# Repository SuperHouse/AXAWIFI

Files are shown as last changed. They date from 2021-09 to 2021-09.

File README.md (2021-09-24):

AXA Electric Window Motor WiFi Controller (ESP8266)
===================================================
Copyright 2017-2021 SuperHouse Automation Pty Ltd  www.superhouse.tv  

An add-in board for AXA domestic electric window mechanisms, to fit
into the battery compartment in place of the AA cells that are normally
installed. It uses an ESP8266 to connect to WiFi, and can then send
control signals to the AXA window motor using LINbus.

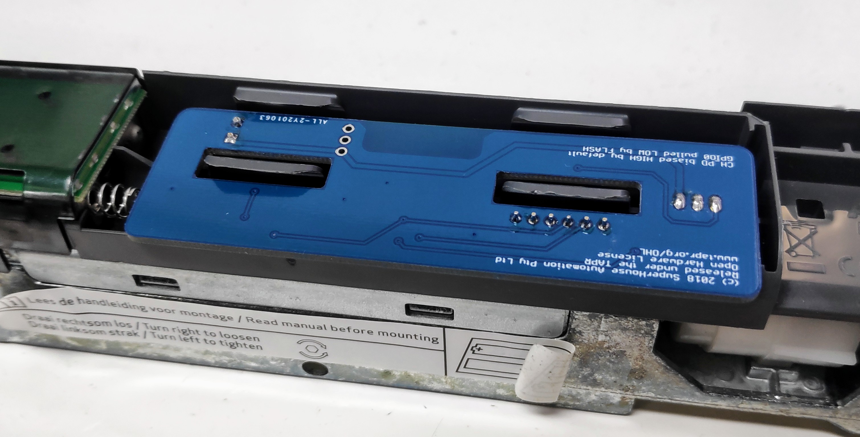
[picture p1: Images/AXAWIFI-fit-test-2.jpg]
Axa Wifi PCB


An external 12Vdc power connection is required. Power is supplied to
the Axa Wifi board, which in turn passes on power and data to the
existing controller in the window motor.

Features:

 * ESP8266 microcontroller with WiFi.
 * LIN bus interface.
 * Fits inside Axa battery compartment.

More information:

  [www.superhouse.tv/axawifi](https://www.superhouse.tv/axawifi)

INSTALLATION
------------
The design is saved as an EAGLE project. Install EAGLE and open the
files directly.

CREDITS
-------
Designed by Jonathan Oxer jon@oxer.com.au

DISTRIBUTION
------------
The specific terms of distribution of this project are governed by the
license referenced below.

LICENSE
-------
Licensed under the TAPR Open Hardware License (www.tapr.org/OHL).
The "license" folder within this repository also contains a copy of
this license in plain text format.

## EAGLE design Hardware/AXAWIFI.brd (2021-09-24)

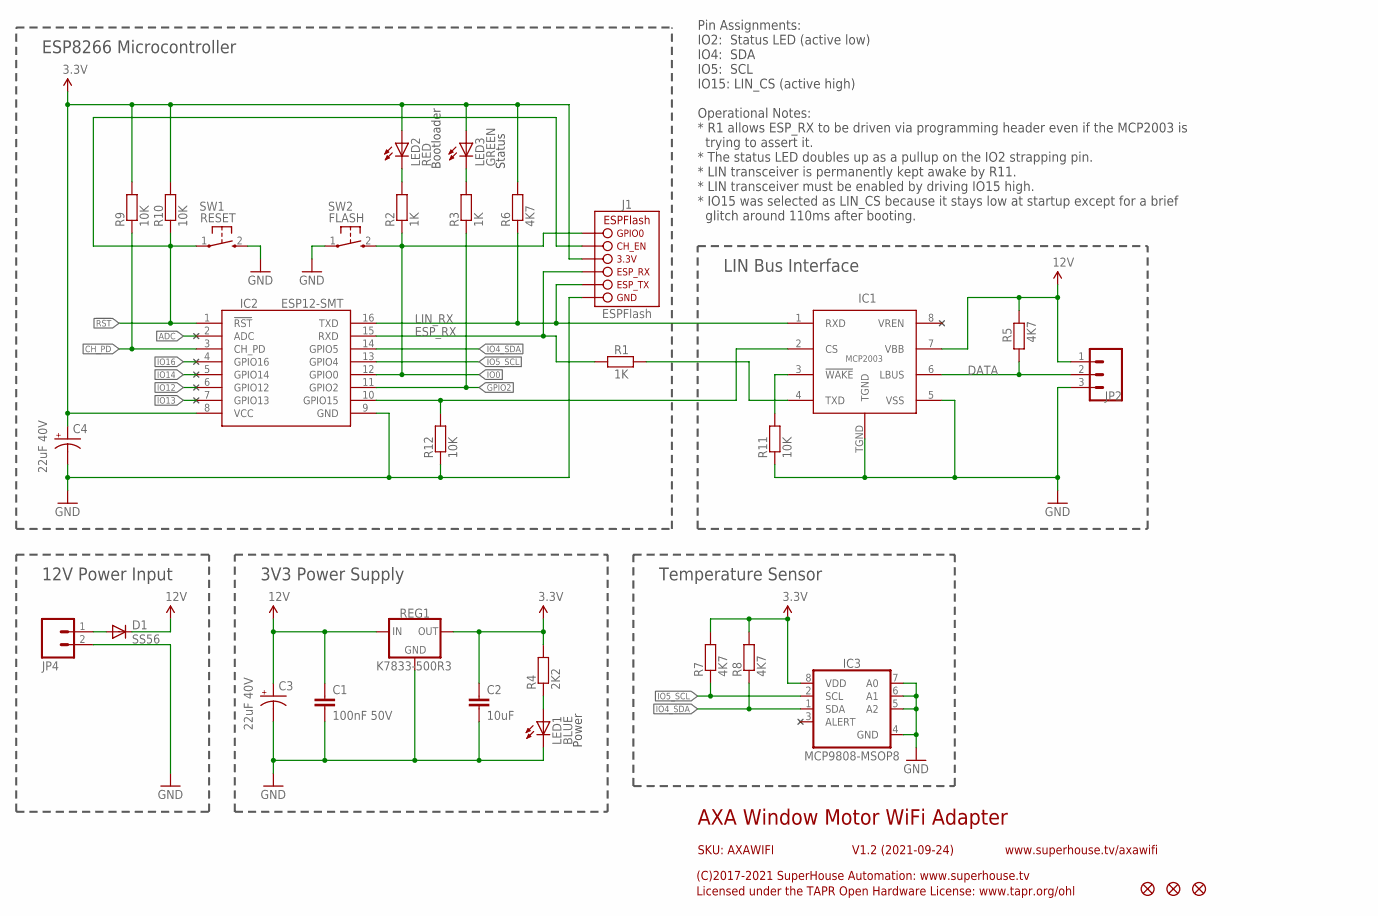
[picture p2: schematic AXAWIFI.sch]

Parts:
C1: 100nF 50V; C0603
C2: 10uF; C0805
C3, C4: 22uF 40V; PANASONIC_C
D1: SS56; SMA-DIODE
FID1, FID2, FID3: FIDUCIAL1X2.5; FIDUCIAL-1X2.5
IC1: MCP2003; SOIC8T
IC2: ESP12-SMT; ESP12
IC3: MCP9808-MSOP8; MSOP-8
J1: ESPFLASH-1X6-2.54-SOCKET; 1X6-2.54-SOCKET
JP2: M03-PLAIN; 1X03
JP4: M02-SCREW-3.5MM; SCREWTERMINAL-3.5MM-2
LED1: BLUE; LED-0603
LED2: RED; LED-0603
LED3: GREEN; LED-0603
R1, R2, R3: 1K; R0603
R4: 2K2; R0603
R5, R6, R7, R8: 4K7; R0603
R9, R10, R11, R12: 10K; R0603
REG1: K7833-500R3; K78XX-500R3
SW1: RESET; TACTILE_SMT_3X4X2
SW2: FLASH; TACTILE_SMT_3X4X2

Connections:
3.3V: C2.1, C4.+, IC2.8 (VCC), IC3.8 (VDD), J1.4 (3.3V), LED2.A, LED3.A, R4.2, R6.2, R7.2, R8.2, R9.2, R10.2, REG1.3 (OUT)
12V: C1.1, C3.+, D1.C, IC1.7 (VBB), JP2.1, R5.2, REG1.1 (IN)
!LIN_WAKE: IC1.3 (!WAKE), R11.2
!RST: IC2.1 (!RST), J1.5 (CH_EN), R10.1, SW1.1
ADC: IC2.2 (ADC)
CH_PD: IC2.3 (CH_PD), R9.1
DATA: IC1.6 (LBUS), JP2.2, R5.1
ESP_RX: IC2.15 (RXD), J1.3 (ESP_RX), R1.1
GND: C1.2, C2.2, C3.-, C4.-, IC1.5 (VSS), IC1.TGND, IC2.9 (GND), IC3.4 (GND), IC3.5 (A2), IC3.6 (A1), IC3.7 (A0), J1.1 (GND), JP2.3, JP4.2, LED1.C, R11.1, R12.1, REG1.2 (GND), SW1.2 (S), SW2.1
GPIO2: IC2.11 (GPIO2), R3.1
GPIO15: IC1.2 (CS), IC2.10 (GPIO15), R12.2
IO0: IC2.12 (GPIO0), J1.6 (GPIO0), R2.1, SW2.2 (S)
IO4_SDA: IC2.14 (GPIO5), IC3.1 (SDA), R8.1
IO5_SCL: IC2.13 (GPIO4), IC3.2 (SCL), R7.1
IO12: IC2.6 (GPIO12)
IO13: IC2.7 (GPIO13)
IO14: IC2.5 (GPIO14)
IO16: IC2.4 (GPIO16)
LIN_RX: IC1.1 (RXD), IC2.16 (TXD), J1.2 (ESP_TX), R6.1
unnamed: D1.A, JP4.1
unnamed: IC1.4 (TXD), R1.2
unnamed: LED3.C, R3.2
unnamed: LED1.A, R4.1
unnamed: LED2.C, R2.2

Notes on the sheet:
AXA Window Motor WiFi Adapter
Power
3V3 Power Supply
SKU: AXAWIFI
(C)2017-2021 SuperHouse Automation: www.superhouse.tv
Licensed under the TAPR Open Hardware License: www.tapr.org/ohl
www.superhouse.tv/axawifi
V1.2 (2021-09-24)
12V Power Input
ESP8266 Microcontroller
LIN Bus Interface
Pin Assignments: IO2: Status LED (active low) IO4: SDA IO5: SCL IO15: LIN_CS (active high) Operational Notes: * R1 allows ESP_RX to be driven via programming header even if the MCP2003 is trying to assert it. * The status LED doubles up as a pullup on the IO2 strapping pin. * LIN transceiver is per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
Temperature Sensor
Bootloader
Status

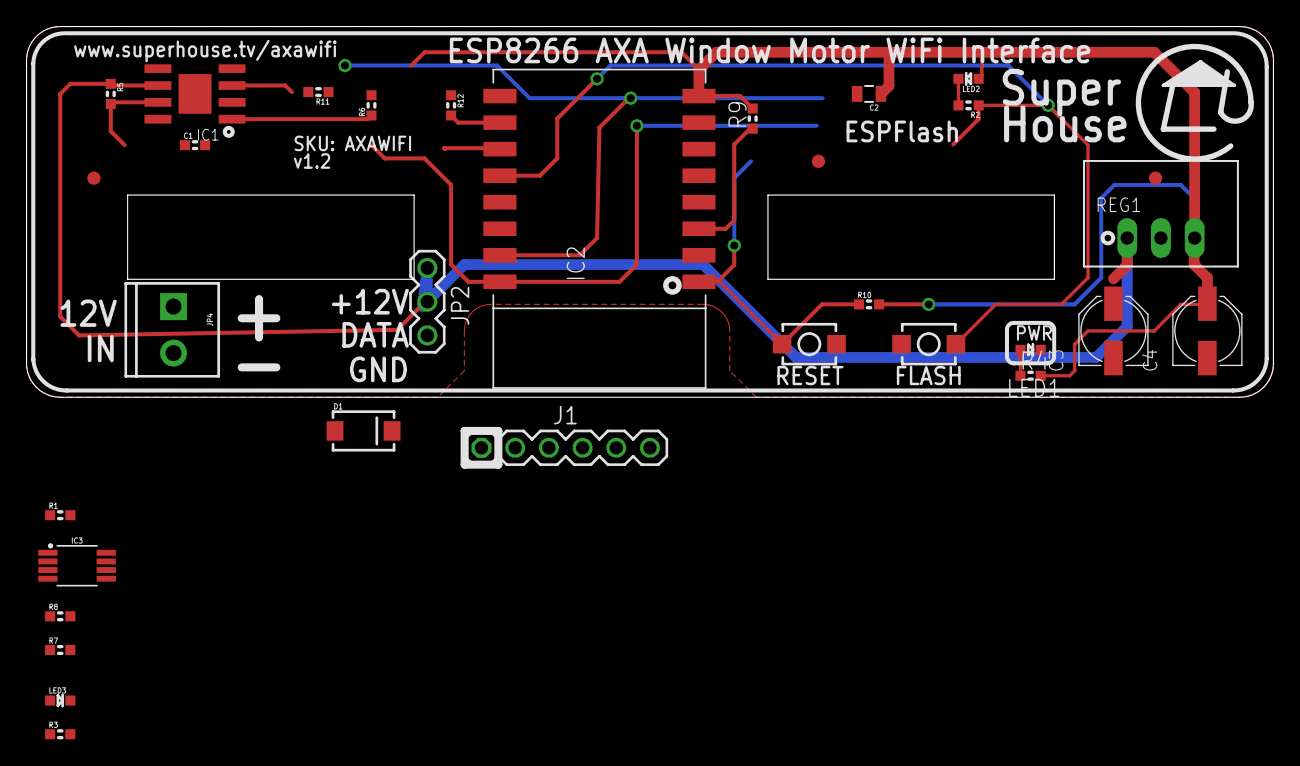
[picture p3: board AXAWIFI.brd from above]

Board: 2 copper layers, 94.0 x 27.9 mm, 32 parts (0 on the bottom side), 19 nets.

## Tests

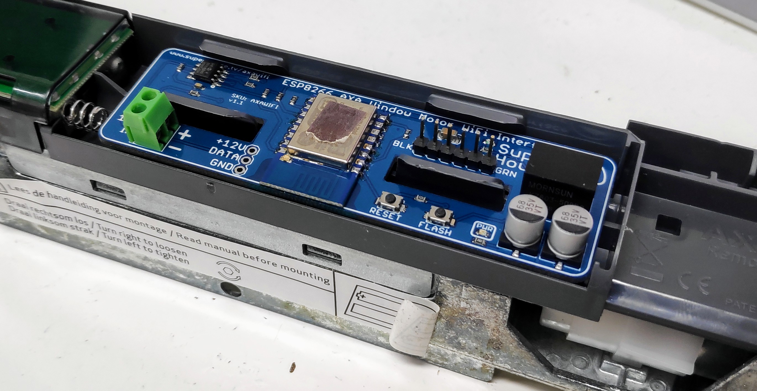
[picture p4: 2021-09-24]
Images/AXAWIFI-fit-test-1.jpg

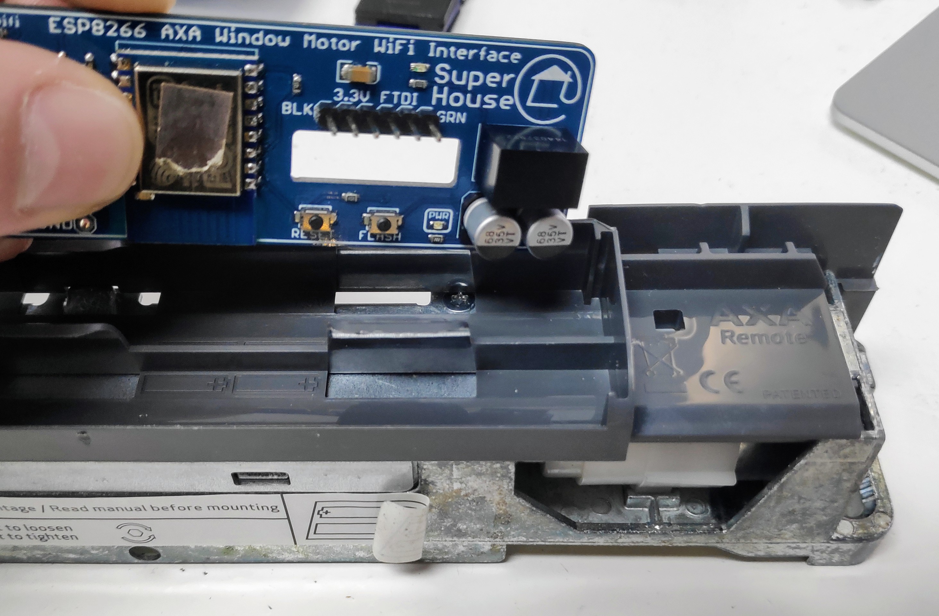
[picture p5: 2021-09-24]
Images/AXAWIFI-fit-test-3.jpg

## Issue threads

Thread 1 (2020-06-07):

Some Tips...

Ivanverdonck, 2020-06-07:
Hi, Thanks for developing this PCB board.

I used the layout and had a online PCB seller make it for me.
Trying to get it to work, and using it i noticed following:

1. RX, TX Pins
I discovered that the two RX,TX pins should be switched on the ESP to get it working using the standard HardwareSerial. To fix this i used a SoftwareSerial and switched the TX and RX pins in the code.

2. 12V is giving some problems (i think)
I tried a 12V power adapter for several months, and it worked perfect, but now i have some problems: The window does not close completely.... It closes so fast it thinks it get jammed when it reaches the end... (even without window attached). When switching to batteries, it closes softley without issues. I ordered a 7,5V/0,8A adapter like the standard one supplied by AXA, hoping this would fix the issue.

Thanks for the compact design of the PCB, i needed to cut some of the plastic of the battery compartment, but now it fits perfectly.

Greetings,
Ivan.

remko2000, 2020-12-05:
Hai Ivan, I ordered this pcb also (the esp12 version). I want to use a script I use also on this one:
[https://www.freetronics.com.au/products/lin-bus-serial-adapter-module#.X8tOTy1x_Uo](url).
This doesn't work. Can I experiment with your code? Can I contact you?

Ivanverdonck, 2020-12-06:
sure, send me a e-mail and i will send u my code: ivan.verdonck(at)gmail.com

Op za 5 dec. 2020 om 10:12 schreef remko2000 <notifications@github.com>:

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

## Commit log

2018-03-22 Initial import of project from June 2017
    [AXAWIFI.brd, AXAWIFI.sch]
2018-06-25 Replaced voltage regulator module with K7833 for v1.1 release
    [AXAWIFI.brd, AXAWIFI.sch]
2019-04-15 Improved clearances
    [AXAWIFI.brd]
2019-09-10 Replaced parts using SuperHouse library
    [AXAWIFI.brd, AXAWIFI.sch]
2019-09-10 Replaced programming header with ESProg header
    [AXAWIFI.brd, AXAWIFI.sch]
2020-05-27 Replace parts using SuperHouse library for 3D models
    [AXAWIFI.brd, AXAWIFI.sch]
2021-09-24 Rearranged project files into more logical structure.
    [AXAWIFI.brd, AXAWIFI.sch]
2021-09-24 Added images of prototype test fits.
2021-09-24 Replaced obsolete programming header with ESPFlash header. Set MCP2003 to be permanently awake. Set MCP2003 to be deselected unless explicitly selected. Major restructure of schematic. Replaced parts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
    [AXAWIFI.brd, AXAWIFI.sch]
2021-09-24 Assigned IO15 as LIN_CS.
    [AXAWIFI.brd, AXAWIFI.sch]
2021-09-24 Rationalised part values and reordered designators.
    [AXAWIFI.brd, AXAWIFI.sch]

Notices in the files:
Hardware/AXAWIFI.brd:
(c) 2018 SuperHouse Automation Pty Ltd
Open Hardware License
